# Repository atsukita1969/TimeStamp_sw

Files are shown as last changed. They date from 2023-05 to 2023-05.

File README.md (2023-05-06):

# 8ボタン　IoTタイムスタンプ
ボタンを押したら、WEB上のgoogle spreadsheetに  
押したボタン番号と時間とステータス(0/1)が記録されます。  
コストパフォーマンス優先で、ESP32-C3-WROOM02-N4を使用しました。  
## Main PCB  
  

## Switch PCB  
  
  
## Switch BOX  

  
## spreadsheetの状態  
  

spreadsheetの設定は下記を参照。  
https://raspberry-pi.nomad-life.net/1917477/memo/esp32%e3%81%a7google%e3%82%b9%e3%83%97%e3%83%ac%e3%83%83%e3%83%89%e3%82%b7%e3%83%bc%e3%83%88%e3%81%ab%e6%9b%b8%e3%81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  

（参考：https://www.haruirosoleil.com/entry/2020/02/02/101937）  
  
## arduino IDE書き込み設定  
arduino IDEの書き込み時の設定は下記。（USB-UARTブリッジ等を使わず、ESP32で内蔵USB-JTAGを使う場合）  


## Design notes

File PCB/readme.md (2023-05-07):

# PCB file
  
eagle / Fusion360

  ## ver 5.10 W/O JTAG bridge version  


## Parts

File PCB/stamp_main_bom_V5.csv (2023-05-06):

Part | Value | Device | Package | Description
BOOT SW | EVQP2 | EVQP2 | EVQP2 | SWITCH TACTILE SPST-NO 0.02A 15V
C1 | 6.3V/330uF | TAJC337K006RNJ | 2312 / 6032 | Tantalum Capacitors - Solid SMD 6.3volts 330uF 20%
C2 | 10nF | C_CHIP-0603(1608-METRIC) | CAPC1608X85 | Capacitor - Generic
C3 | 6.3V/330uF | TAJC337K006RNJ | 2312 / 6032 | Tantalum Capacitors - Solid SMD 6.3volts 330uF 20%
C4 | 0.1uF | C_CHIP-0603(1608-METRIC) | CAPC1608X85 | Capacitor - Generic
C5 | 0.1uF | C_CHIP-0603(1608-METRIC) | CAPC1608X85 | Capacitor - Generic
C6 | 47pF | C_CHIP-0805(2012-METRIC) | CAPC2012X110 | Capacitor - Generic
C7 | 47pF | C_CHIP-0805(2012-METRIC) | CAPC2012X110 | Capacitor - Generic
C8 | 0.1uF | C_CHIP-0603(1608-METRIC) | CAPC1608X85 | Capacitor - Generic
C9 | 0.1uF | C_CHIP-0603(1608-METRIC) | CAPC1608X85 | Capacitor - Generic
C10 | 0.1uF | C_CHIP-0603(1608-METRIC) | CAPC1608X85 | Capacitor - Generic
ESP32-C3-WR-02 | ESP32-C3-WROOM-02-N4 | ESP32-C3-WROOM-02-N4 | MODULE_ESP32-C3-WROOM-02-H4 | WiFi Modules (802.11) (Engineering Samples) SMD module, ESP32-C3, 4MB SPI flash, PCB antenna, -40 C +105 C Check availability Check availability
F1 | PTC0603 | PTC0603 | 0603 | Resettable Fuse PTC
IC1 | LM7805_SOT223 | LM7805_SOT223 | SOT230P700X170-4 | 5V Voltage Regulator
IO3 LED | LED_RED | LED_CHIP_RED-1608 | LEDC1608X39N_R | LED - Generic
J1 | S5B-PH-K-S(LF)(SN) | S5B-PH-K-S(LF)(SN) | S5B-PH-K-S(LF)(SN) | JST PH conn (5)
J2 | header pin (3) | CONN_03 | 1X03
J3 | header pin (3) | CONN_03 | 1X03
POW LED | LED_RED | LED_CHIP_RED-1608 | LEDC1608X39N_R | LED - Generic
Q1 | 2SC3838T146 | 2SC3838T146 | SC59 | NPN bi-pol transistor
Q2 | 2SC3838T146 | 2SC3838T146 | SC59 | NPN bi-pol transistor
R1 | 10k | R-US_R0805 | R0805 | RESISTOR, American symbol
R2 | 330ohm | R-US_R0805 | R0805 | RESISTOR, American symbol
R3 | 10k | R-US_R0805 | R0805 | RESISTOR, American symbol
R4 | 10k | R-US_R0805 | R0805 | RESISTOR, American symbol
R5 | 330ohm | R-US_R0805 | R0805 | RESISTOR, American symbol
R6 | 27ohm | R-US_R0805 | R0805 | RESISTOR, American symbol
R7 | 27ohm | R-US_R0805 | R0805 | RESISTOR, American symbol
R8 | 27ohm | R-US_R0805 | R0805 | RESISTOR, American symbol
R9 | 27ohm | R-US_R0805 | R0805 | RESISTOR, American symbol
R10 | 10k | R-US_R0805 | R0805 | RESISTOR, American symbol
R11 | 10k | R-US_R0805 | R0805 | RESISTOR, American symbol
RST SW | EVQP2 | EVQP2 | EVQP2 | SWITCH TACTILE SPST-NO 0.02A 15V
T1 | NPN digital transistor | NPN_DRIVER-SC59-BEC | SC59-BEC | NPN Bias Resistor Transistor
X1 | ZX62-B-5PA(11) | ZX62-B-5PA(11) | ZX62-B-5PA(11) | Micro USB Connector HI-SPEED Certified

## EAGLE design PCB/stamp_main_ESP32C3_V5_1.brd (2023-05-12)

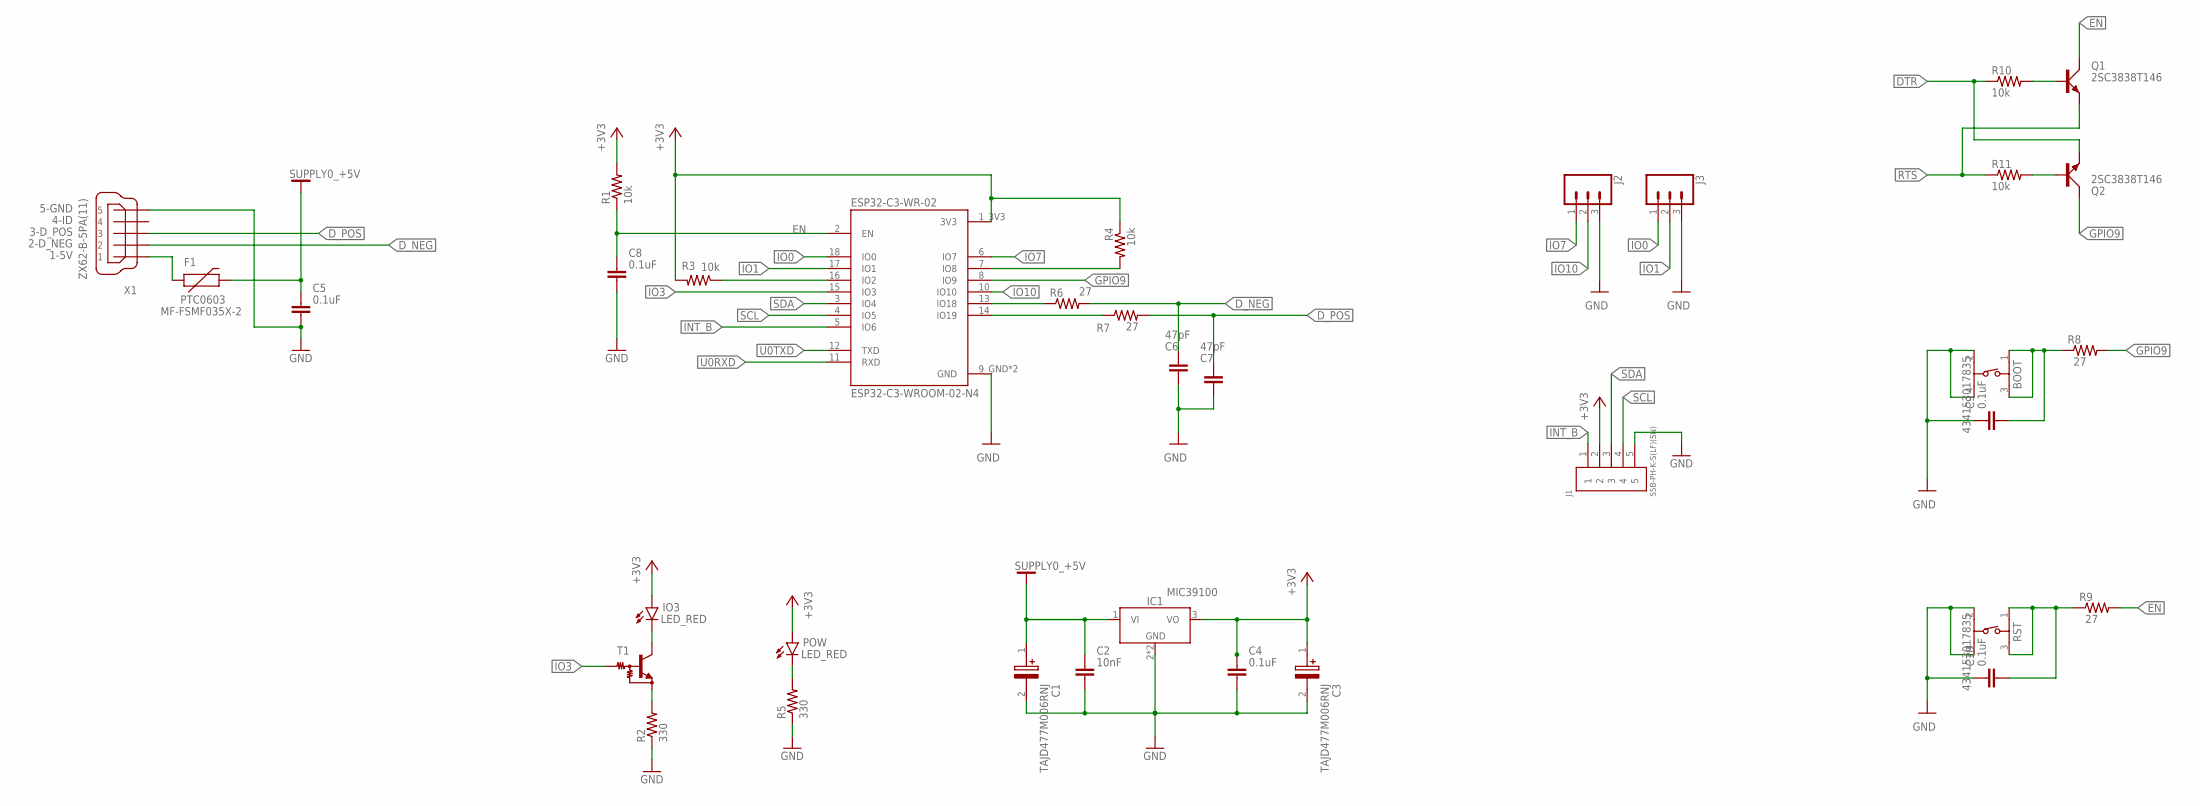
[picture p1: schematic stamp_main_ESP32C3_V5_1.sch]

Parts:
BOOT: 434153017835
C1, C3: TAJD477M006RNJ; CAPPM7344X310N
C2: 10nF; CAPC1608X85
C4, C5, C8, C9, C10: 0.1uF; CAPC1608X85
C6, C7: 47pF; CAPC2012X110
ESP32-C3-WR-02: ESP32-C3-WROOM-02-N4; MODULE_ESP32-C3-WROOM-02-H4
F1: PTC0603; 0603
IC1: LM7805_SOT223; SOT230P700X170-4
IO3: LED_RED; LEDC1608X39N_R
J1: S5B-PH-K-S(LF)(SN)
J2, J3: CONN_03; 1X03
POW: LED_RED; LEDC1608X39N_R
Q1, Q2: 2SC3838T146; SC59
R1, R3, R4, R10, R11: 10k; R0805
R2, R5: 330; R0805
R6, R7, R8, R9: 27; R0805
RST: 434153017835
T1: MUN2211T1-NPN_DRIVER-SC59-BEC; SC59-BEC
X1: ZX62-B-5PA(11)

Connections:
+3V3: C3.1 (+), C4.1, ESP32-C3-WR-02.1_3V3 (3V3), IC1.3 (VO), IO3.2 (A), J1.2, POW.2 (A), R1.2, R3.2, R4.1
+5V: C1.1 (+), C2.1, C5.1, F1.2, IC1.1 (VI)
DTR: Q2.E, R10.1
D_NEG: C6.1, R6.2, X1.2
D_POS: C7.1, R7.2, X1.3
EN: C8.1, ESP32-C3-WR-02.2 (EN), Q1.C, R1.1, R9.2
GND: BOOT.2 (3), BOOT.4, C1.2 (-), C2.2, C3.2 (-), C4.2, C5.2, C6.2, C7.2, C8.2, C9.1, C10.1, ESP32-C3-WR-02.9_GND (GND), ESP32-C3-WR-02.P$1_GND (GND), IC1.2 (GND), IC1.4 (GND), J1.5, J2.3, J3.3, R2.1, R5.1, RST.2 (3), RST.4, X1.5
GPIO9: ESP32-C3-WR-02.8 (IO9), Q2.C, R8.2
INT_B: ESP32-C3-WR-02.5 (IO6), J1.1
IO0: ESP32-C3-WR-02.18 (IO0), J3.1
IO1: ESP32-C3-WR-02.17 (IO1), J3.2
IO3: ESP32-C3-WR-02.15 (IO3), T1.B
IO7: ESP32-C3-WR-02.6 (IO7), J2.1
IO10: ESP32-C3-WR-02.10 (IO10), J2.2
unnamed: ESP32-C3-WR-02.16 (IO2), R3.1
unnamed: ESP32-C3-WR-02.7 (IO8), R4.2
unnamed: F1.1, X1.1
unnamed: C10.2, R9.1, RST.1, RST.3 (2)
unnamed: IO3.1 (C), T1.C
unnamed: BOOT.1, BOOT.3 (2), C9.2, R8.1
unnamed: Q1.B, R10.2
unnamed: Q2.B, R11.2
unnamed: POW.1 (C), R5.2
unnamed: R2.2, T1.E
unnamed: ESP32-C3-WR-02.13 (IO18), R6.1
unnamed: ESP32-C3-WR-02.14 (IO19), R7.1
RTS: Q1.E, R11.1
SCL: ESP32-C3-WR-02.4 (IO5), J1.4
SDA: ESP32-C3-WR-02.3 (IO4), J1.3
U0RXD: ESP32-C3-WR-02.11 (RXD)
U0TXD: ESP32-C3-WR-02.12 (TXD)

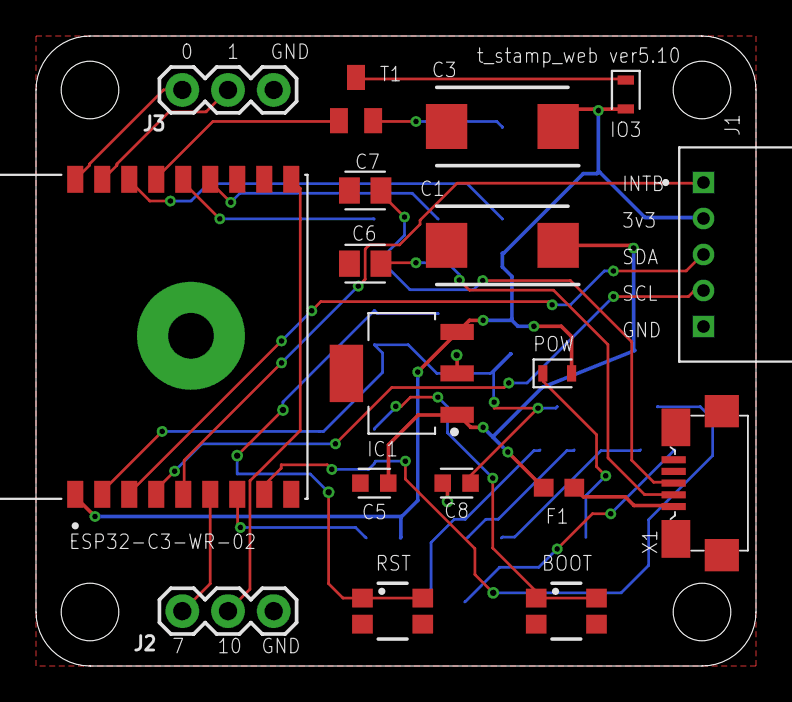
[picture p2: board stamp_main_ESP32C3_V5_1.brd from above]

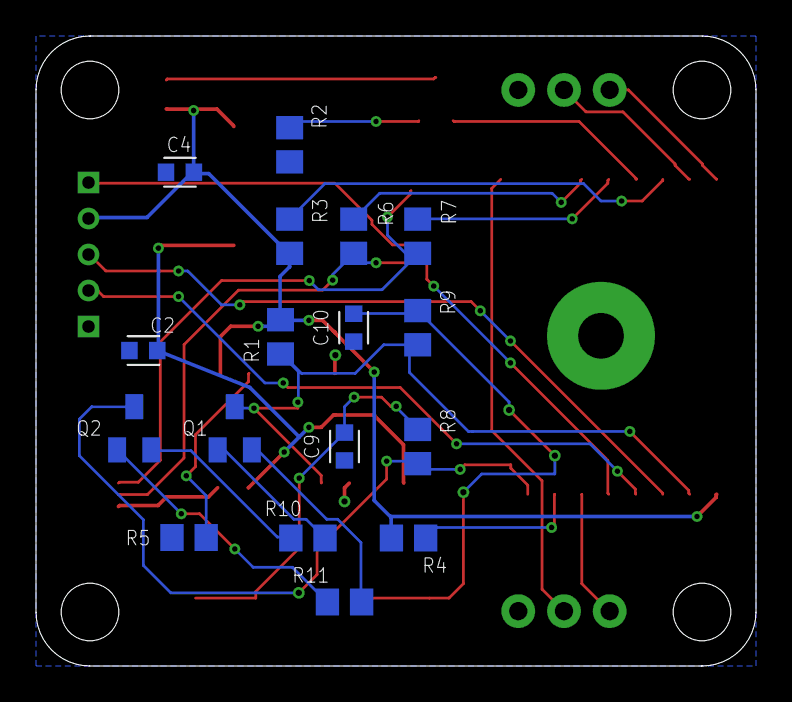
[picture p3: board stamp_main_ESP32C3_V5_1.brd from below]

Board: 2 copper layers, 40.0 x 35.0 mm, 35 parts (17 on the bottom side), 29 nets.

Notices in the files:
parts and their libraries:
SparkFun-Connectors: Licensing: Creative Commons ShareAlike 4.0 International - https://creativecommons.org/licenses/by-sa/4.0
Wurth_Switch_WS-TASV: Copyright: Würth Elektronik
